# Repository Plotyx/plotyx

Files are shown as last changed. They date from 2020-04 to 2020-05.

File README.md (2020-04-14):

## Plotyx - Open-source XY plotter
Plotyx is an open-source XY pen plotter, built using a mix of 3D printed and off-the-shelf parts. It focus on using linear rails for precise movement and accuracy, and provides a working area of just over A3 paper size.  
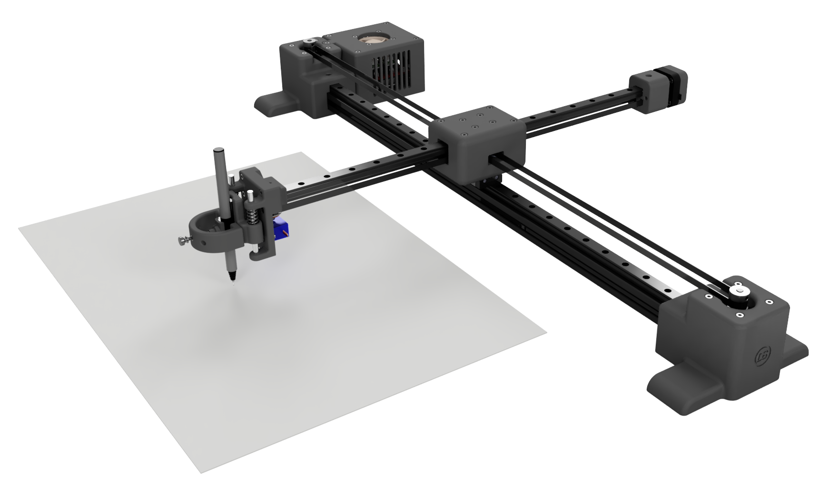
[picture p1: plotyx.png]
<br>

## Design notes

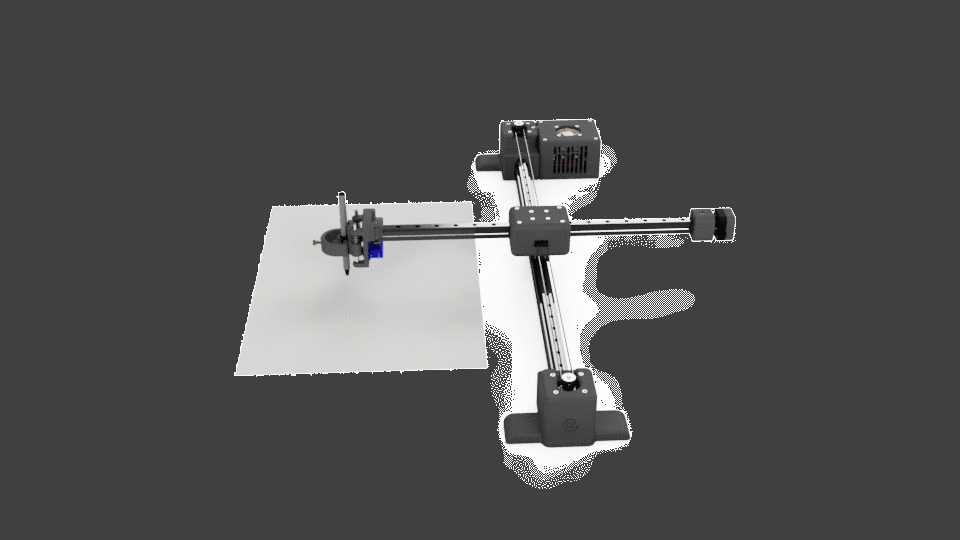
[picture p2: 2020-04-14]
plotyx.gif

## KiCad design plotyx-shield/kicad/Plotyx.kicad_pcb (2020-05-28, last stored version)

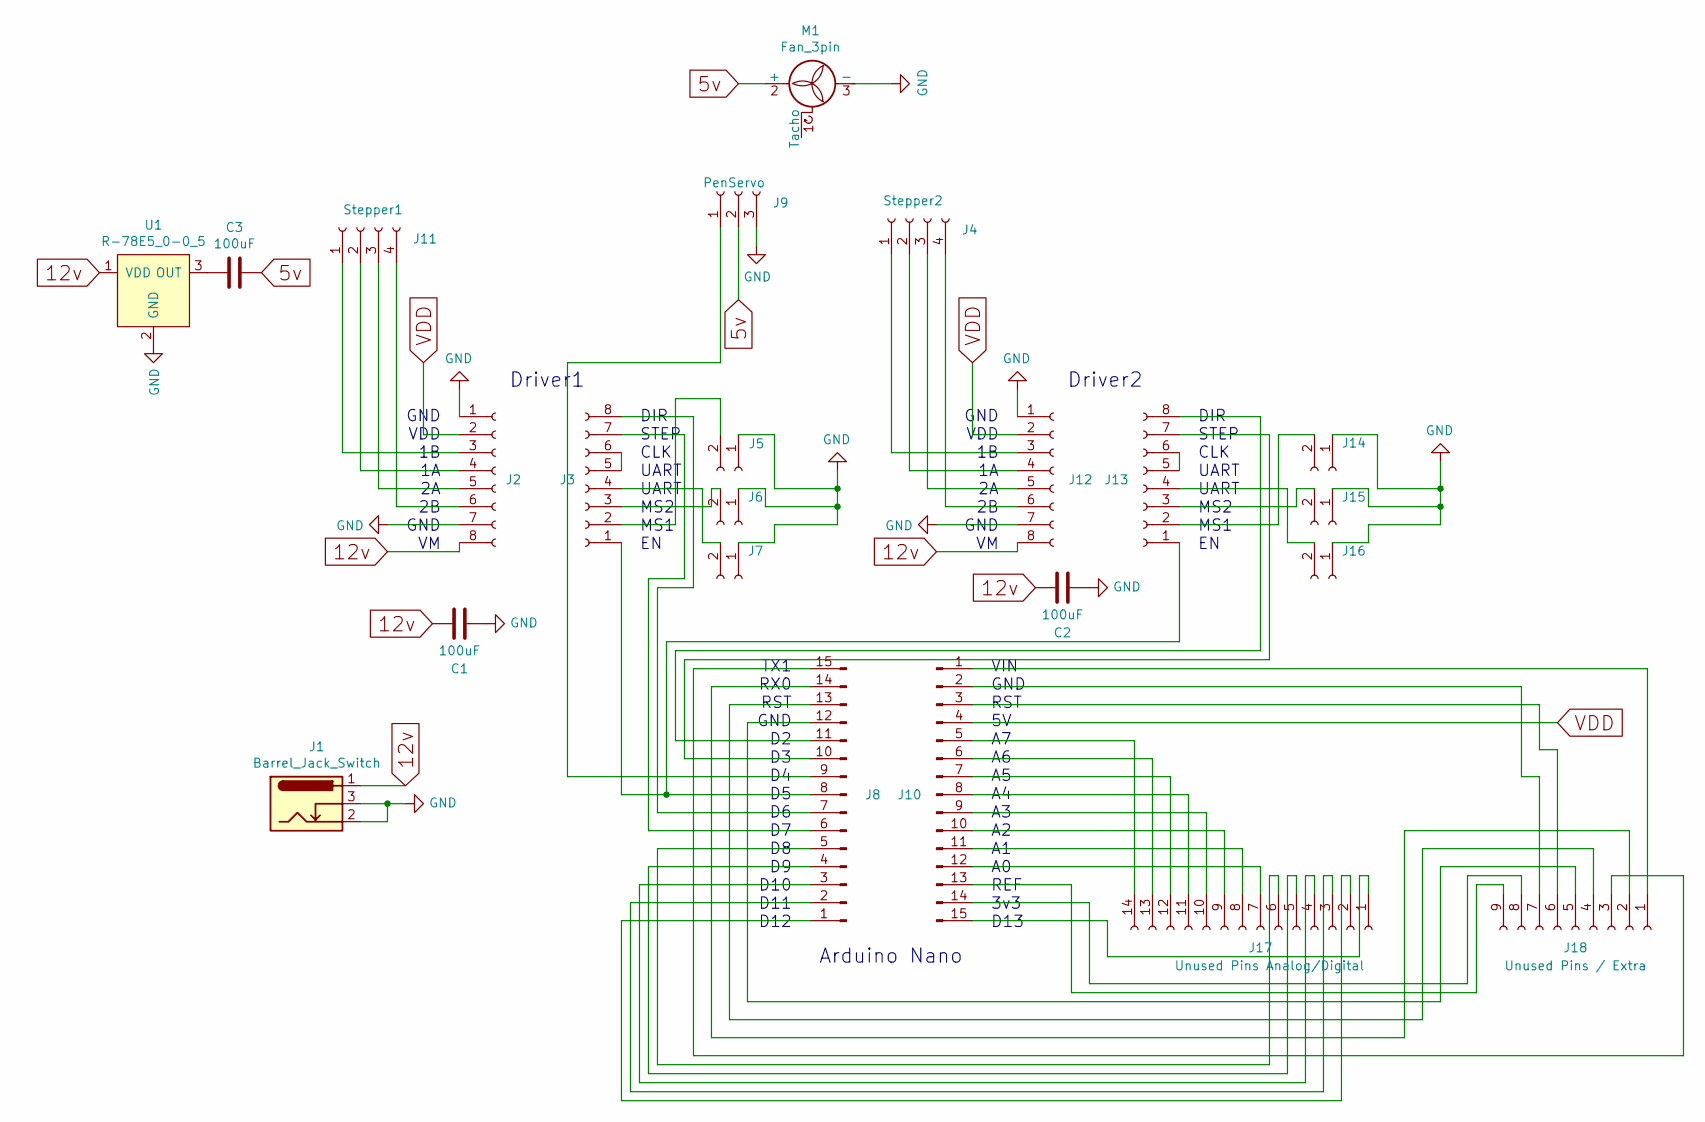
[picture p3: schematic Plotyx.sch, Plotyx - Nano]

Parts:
C1, C2, C3: 100uF; C_Radial_D5.0mm_H11.0mm_P2.00mm
J1: Barrel_Jack_Switch; BarrelJack_Horizontal
J2, J3, J12, J13: Conn_01x08_Female; PinSocket_1x08_P2.54mm_Vertical
J4: Stepper2; PinHeader_1x04_P2.54mm_Vertical
J5, J6, J7, J14, J15, J16: Conn_01x02_Female; PinHeader_1x02_P2.54mm_Vertical
J8, J10: Conn_01x15_Male; PinSocket_1x15_P2.54mm_Vertical
J9: PenServo; PinHeader_1x03_P2.54mm_Vertical
J11: Stepper1; PinHeader_1x04_P2.54mm_Vertical
J17: Unused Pins Analog/Digital; PinSocket_1x14_P2.54mm_Vertical
J18: Unused Pins / Extra; PinSocket_1x09_P2.54mm_Vertical
M1: Fan_3pin; FanPinHeader_1x03_P2.54mm_Vertical
U1: R-78E5_0-0_5; SIP-3_P2.54mm; MPN R-78E5.0-0.5; Digi-Key_PN 945-1648-5-ND

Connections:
5v: C3.1, J9.2, M1.2 (+)
12v: C1.2, C2.2, J1.1, J2.8, J12.8, U1.1 (VDD)
GND: C1.1, C2.1, J1.2, J1.3, J2.1, J2.7, J5.1, J6.1, J7.1, J9.3, J12.1, J12.7, J14.1, J15.1, J16.1, M1.3 (-), U1.2 (GND)
unnamed: C3.2, U1.3 (OUT)
unnamed: J3.2, J5.2
unnamed: J3.3, J6.2
unnamed: J3.4, J7.2
unnamed: J3.5, J3.6
unnamed: J3.7, J8.6
unnamed: J3.8, J8.7
unnamed: J8.9, J9.1
unnamed: J10.1, J18.1
unnamed: J10.2, J18.7
unnamed: J10.3, J18.6
unnamed: J10.5, J17.14
unnamed: J10.6, J17.13
unnamed: J10.7, J17.12
unnamed: J10.8, J17.11
unnamed: J10.9, J17.10
unnamed: J10.10, J17.9
unnamed: J10.11, J17.8
unnamed: J10.12, J17.7
unnamed: J10.13, J18.9
unnamed: J10.14, J18.8
unnamed: J10.15, J17.1
unnamed: J2.3, J11.1
unnamed: J2.4, J11.2
unnamed: J2.5, J11.3
unnamed: J2.6, J11.4
unnamed: J4.1, J12.3
unnamed: J4.2, J12.4
unnamed: J4.3, J12.5
unnamed: J4.4, J12.6
unnamed: J3.1, J8.8, J13.1
unnamed: J13.2, J14.2
unnamed: J13.3, J15.2
unnamed: J13.4, J16.2
unnamed: J13.5, J13.6
unnamed: J8.10, J13.7
unnamed: J8.11, J13.8
unnamed: J8.1, J17.2
unnamed: J8.2, J17.3
unnamed: J8.3, J17.4
unnamed: J8.4, J17.5
unnamed: J8.5, J17.6
unnamed: J8.14, J18.2
unnamed: J8.15, J18.3
unnamed: J8.13, J18.4
unnamed: J8.12, J18.5
VDD: J2.2, J10.4, J12.2

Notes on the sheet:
GND VDD 1B 1A 2A 2B GND VM
DIR STEP CLK UART UART MS2 MS1 EN
Driver2
Driver1
Arduino Nano
VIN GND RST 5V A7 A6 A5 A4 A3 A2 A1 A0 REF 3v3 D13
TX1 RX0 RST GND D2 D3 D4 D5 D6 D7 D8 D9 D10 D11 D12

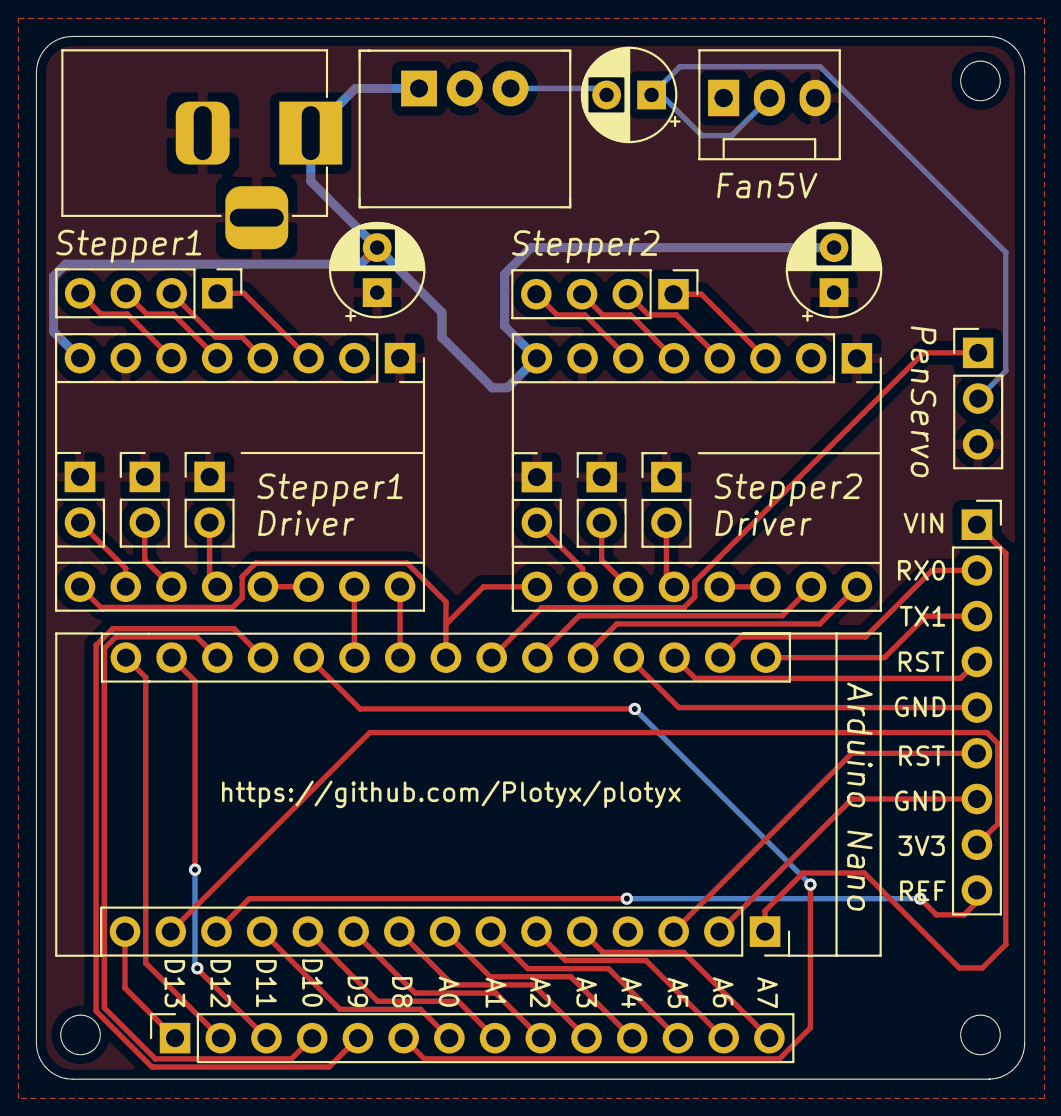
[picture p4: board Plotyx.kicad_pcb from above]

Board: 2 copper layers, 54.9 x 57.9 mm, 23 parts (0 on the bottom side), 50 nets.

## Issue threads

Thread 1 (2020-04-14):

Create a BOM list

morozgrafix, 2020-04-14:
While design is in progress we can start making a Bill Of Materials with links to the parts sources. I think it would be helpful to have multiple sources if available for people located in different parts of the world.

diogorsergio, 2020-04-14:
I'll investigate the functionality inside Fusion360 as mentioned here: https://www.autodesk.com/products/fusion-360/blog/quick-tip-export-boms/. It can save us some work on listing all the hardware parts used in the design and it can also be helpfull for creating simple instructions of the build process.

morozgrafix, 2020-04-14:
That's a great idea, I can write a script to convert CSV into markdown if needed.

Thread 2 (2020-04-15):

Stepper housing - Openings in the walls.

diogorsergio, 2020-04-15:
**Notes:**
May consider opening some of the walls in to allow air to circulated to the stepper motors in case they run warm inside of the fully enclosed housing. Hopefully this doesn't compromise rigidity of the assembly.

diogorsergio, 2020-04-15:
Added some vents to the side walls, this should help. I think the rigidity of the part is not affected much, the wall is quite thick with 7mm.

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

morozgrafix, 2020-04-15:
Nice. It matches the theme. Are they on the both sides?

diogorsergio, 2020-04-15:
Yeah, both sides walls on both feet. There was clash with the feet that is coupled with the electronics box, but I opened vents in it too. Now it might be better because of the fan airflow, or worse if the fan blows hot air from the electronics into the motor housing. I think it should be fine.

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

morozgrafix, 2020-04-15:
This is fantastic. I think it's both functional and has pleasing aesthetics. If fan is pulling air out of the box then I would think it will pull air from the motor as well. I'll inspect cross section of the model to get some more details on the vents.

Closed 2020-05-28.

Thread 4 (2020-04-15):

Stepper Motor - Cover

diogorsergio, 2020-04-15:
**Notes:**
Cover to prevent snags and jams on the belt. Maybe magnetic attachment with the motor screws?

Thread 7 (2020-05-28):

Plotyx - Arduino Nano Shield

diogorsergio, 2020-05-28:
Create a custom PCB shield for the Arduino Nano. The shield needs to run GRBL and operate two stepper drivers TMC2208 (or similar like A4988, DRV8825), the pen servo and a 5V fan.

The idea for the custom pcb came from Nebulus Design and their own similar PCB, this version just builds on top of his design and adds a couple more features.

The Plotyx design electronics box will have several versions to accept various boards including, Arduino Uno + CNC Shield, Arduino Nano + Plotyx Shield and the EBB Driver Board.

diogorsergio, 2020-05-28:
Work done in: https://github.com/Plotyx/plotyx/commit/cbe2742f9ee31cb3b8d7c173fff252763f118fa1

Closed 2020-05-28.

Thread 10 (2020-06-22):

Belt End - Simplify Mechanism

diogorsergio, 2020-06-22:
**Notes:**
The current mechanism to tighten the belts is overly complex. Needs to be simplied.

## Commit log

2020-05-28 Added Arduino Plotyx Shield project files
    [Plotyx-B_Cu.gbr, Plotyx-B_Mask.gbr, Plotyx-B_SilkS.gbr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]
2020-06-22 Removing Support for Plotyx-Shield
    [Plotyx-B_Cu.gbr, Plotyx-B_Mask.gbr, Plotyx-B_SilkS.gbr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]

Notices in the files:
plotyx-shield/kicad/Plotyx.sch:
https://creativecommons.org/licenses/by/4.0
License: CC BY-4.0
